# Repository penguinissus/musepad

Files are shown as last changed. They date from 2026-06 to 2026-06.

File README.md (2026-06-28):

# Musepad
This is a macropad that is built for helping with complicated functions when writing music in MuseScore. This macropad also features a compact and minimalistic design so it looks nice, and a plateless design which uses less material and provides more flex to each individual key.  

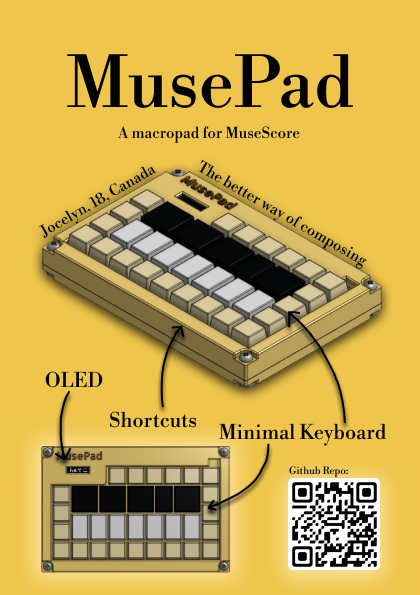
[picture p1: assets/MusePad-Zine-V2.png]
Zine
  

# User Instructions
Assembly:  
1. print out and buy all the parts found in `MusePad BOM.csv`   
2. solder everything together  
3. put in the keycaps accordingly (please refer to `3d models prints/Full Assembly.step` or reference pictures below for ideal layout)  
4. connect the oled to the pins on the PCB using jumper wires
5. sandwich pcb between the top and the bottom case  

Firmware:  
1. go to [circuitpython.org/downloads](circuitpython.org/downloads)    
2. download circuitpython for raspberry pi pico  
3. plug in keyboard to laptop and make sure to use a data transmitting cable  
4. open up the pico folder in your computer's directory  
5. replace the content of `code.py` in the pico folder with the one in this repo (`root://code/code.py`) 

# Why and how did I make it
I love composing music, and MuseScore is one great free composing software. However, whenever I want to compose efficiently, musescore hinders me significantly. Each detail I add to the music either requires too much shortcut memorization or it would take ages to find so I built MusePad to solve this problem. 

I first came up with some drawings of the design to make sure I knew how the layout kind of looked like. Then I made the schematic and PCB design on keycad, mostly following a tutorial (refer to the first resource link). I made the CAD on onshape mostly using skills I already had based on my past experiences, and for details that I don't really know, I referenced the hackpad guide (link no.2 in resource section). I also learned how to cad a keycap following a youtube tutorial (link no.3) which was really interesting. 

# Diagrams
Schematic Diagram:  
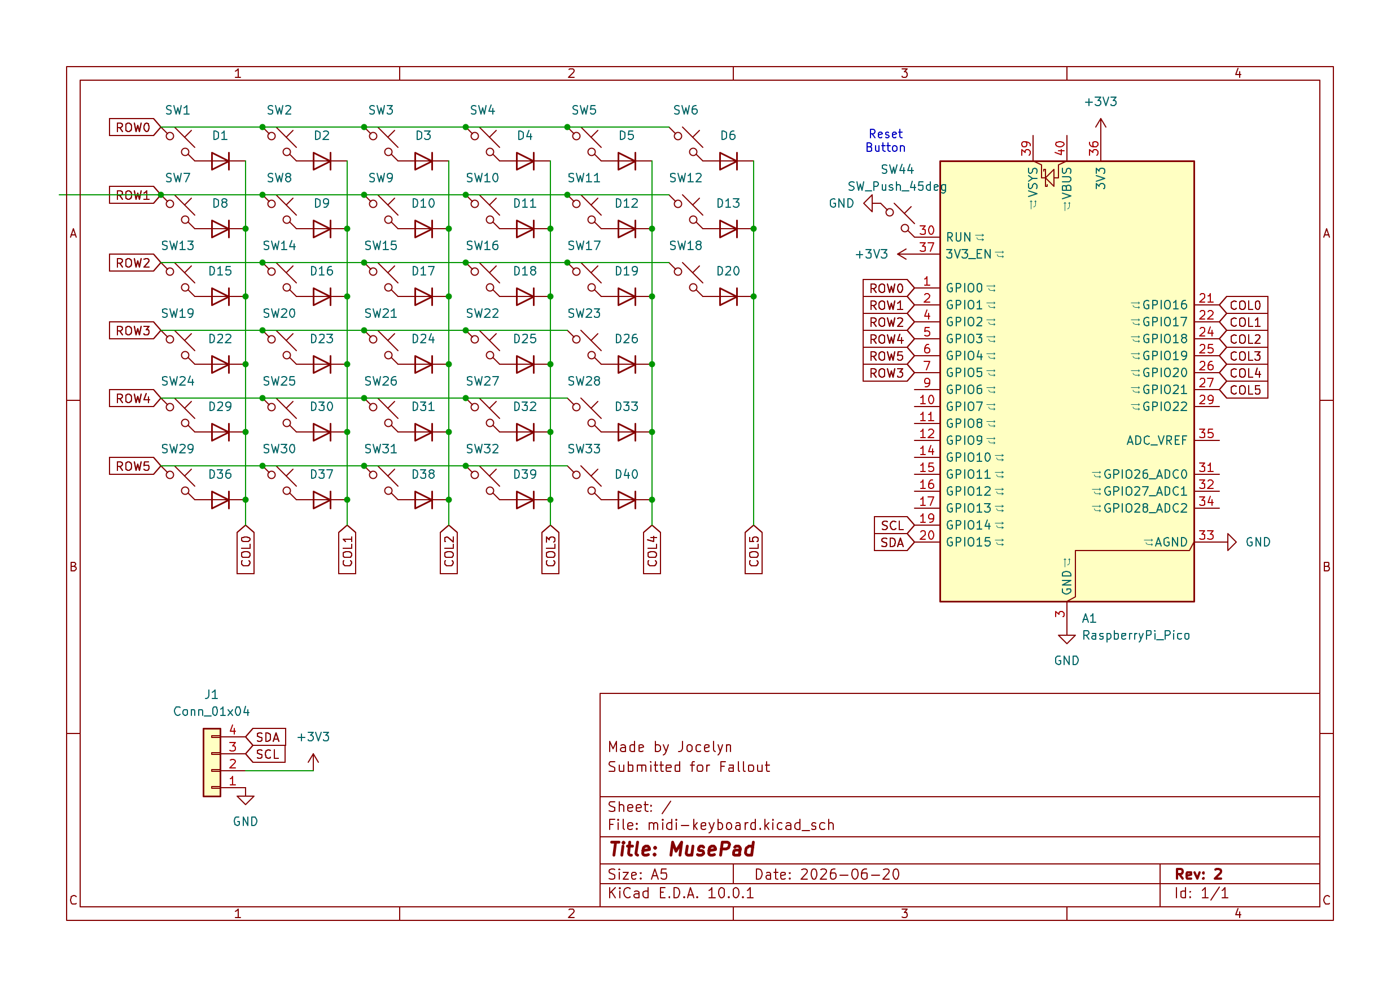
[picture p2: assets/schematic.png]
Schematic Diagram
  
PCB Editor View:  
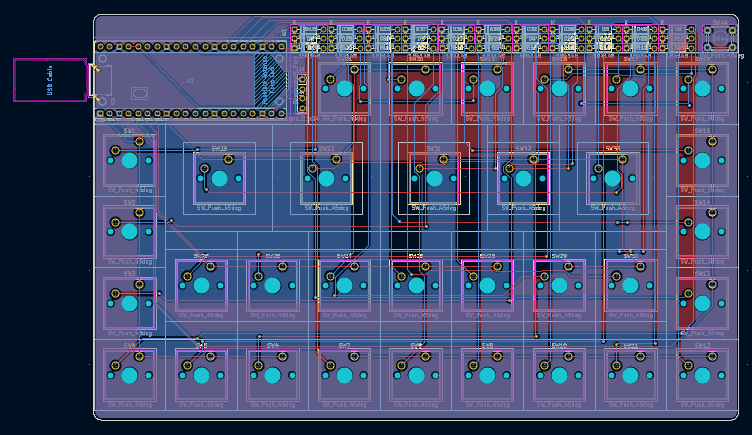
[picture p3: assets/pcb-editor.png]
PCB Editor View
  
PCB Model:  
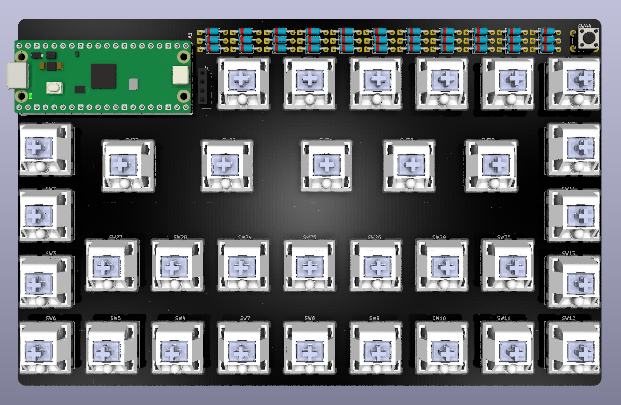
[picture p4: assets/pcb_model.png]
PCB Model
  
Assembled Model:  
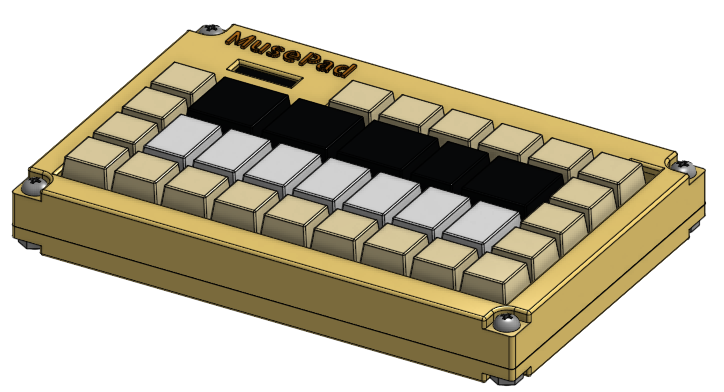
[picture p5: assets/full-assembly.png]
3D Model
  

# Resources
1. the blueprint tutorial  
2. hackpad guide  
3. youtube

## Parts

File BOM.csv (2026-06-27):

 | # | Price | Details
CHERRY MX | 33 | $5.63 | Any would work | https://www.amazon.ca/Mechanical-Keyboard-Switches-Compatible-Replaceable/dp/B0GT96R2XL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
Diodes | 33 | $3.65 | 1N4148 | https://www.amazon.ca/Switching-Electronic-Conponents-Assortment-Practical/dp/B0GJL8PR9D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
Push Button | 1 | $1.95 | 6mm | https://www.amazon.ca/Yevison-Tactile-Momentary-Button-Creative/dp/B0816XTT2P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
Raspberry Pi Pico | 1 | $6.85 | https://www.amazon.ca/CorpShadow-RPIPICO-Raspberry-Pi-Pico/dp/B09YJ34CK3
OLED Display | 1 | $4.94 | 0.91 Inch White OLED Display Module I2C Interface |  | https://www.amazon.ca/Serial-Display-Module-128X64-SSD1306/dp/B08F7M2RZ9
PCB | 1 | $12.30 | https://github.com/penguinissus/musepad/tree/main/production
Case Bottom | 1 | $0.00 | https://github.com/penguinissus/musepad/blob/main/3d%20models%20prints/Case%20Bottom.step
Case Top | 1 | $0.00 | https://github.com/penguinissus/musepad/blob/main/3d%20models%20prints/Case%20Top.step
Keycap normal size | 21 | $0.00 | https://github.com/penguinissus/musepad/blob/main/3d%20models%20prints/Keycap%201x1.step
Keycap white tall | 7 | $0.00 | https://github.com/penguinissus/musepad/blob/main/3d%20models%20prints/Keycap%201x1.5.step
Keycap black tall | 1 | $0.00 | https://github.com/penguinissus/musepad/blob/main/3d%20models%20prints/Keycap%201x1.5%20Black.step
Keycap black fat | 4 | $0.00 | https://github.com/penguinissus/musepad/blob/main/3d%20models%20prints/Keycap%201.5x1.5%20Black.step
Total price | $35.32

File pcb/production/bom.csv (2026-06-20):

Designator | Footprint | Quantity | Value | LCSC Part #
A1 | RaspberryPi_Pico_Common_THT | 1 | RaspberryPi_Pico
D1, D10, D11, D12, D13, D15, D16, D17, D18, D19, D2, D20, D22, D23, D24, D25, D26, D29, D3, D30, D31, D32, D33, D36, D37, D38, D39, D4, D40, D5, D6, D8, D9 | D_DO-35_SOD27_P7.62mm_Horizontal | 33 | 1N4148
J1 | PinSocket_1x04_P2.54mm_Vertical | 1 | Conn_01x04
SW1, SW10, SW11, SW12, SW13, SW14, SW15, SW16, SW17, SW18, SW19, SW2, SW20, SW21, SW22, SW23, SW24, SW25, SW26, SW27, SW28, SW29, SW3, SW30, SW31, SW32, SW33, SW4, SW5, SW6, SW7, SW8, SW9 | SW_Cherry_MX_1.00u_PCB | 33 | SW_Push_45deg
SW44 | SW_PUSH_6mm | 1 | SW_Push_45deg

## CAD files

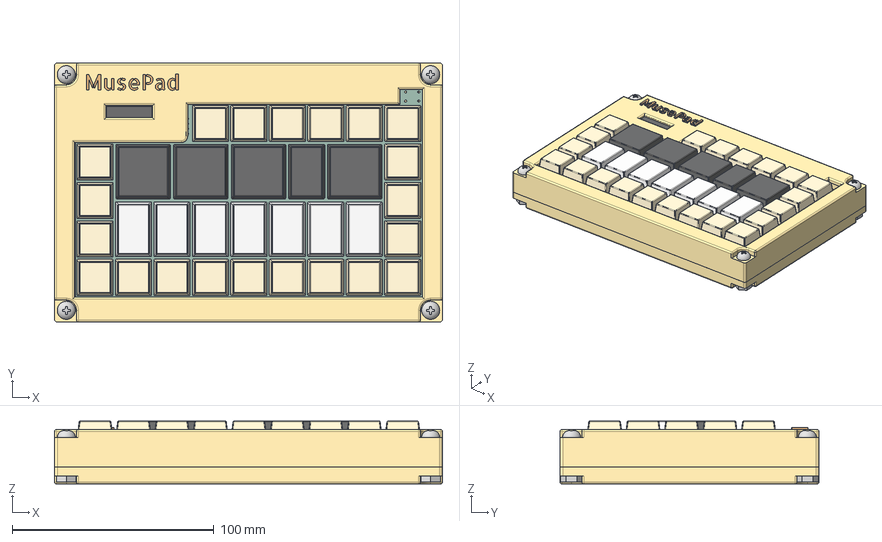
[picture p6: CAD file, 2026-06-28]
3d-models-prints/Full-Assembly.step
192.2 x 128.4 x 31.2 mm
midi-keyboard_PCB

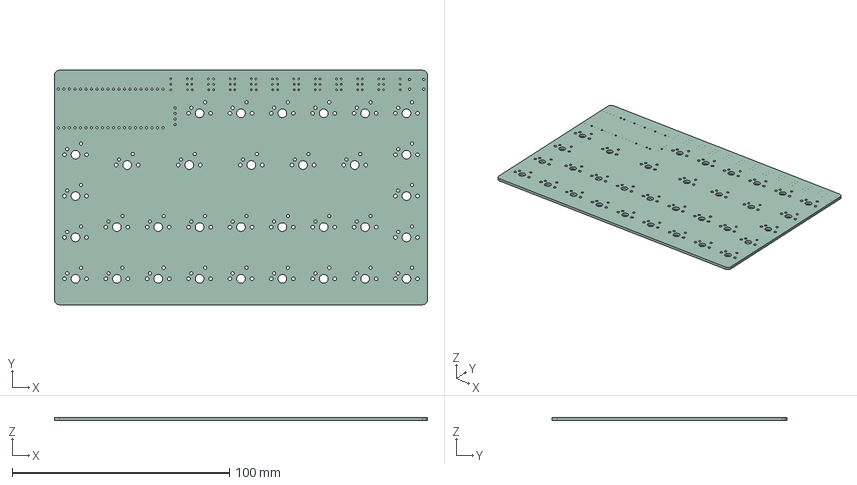
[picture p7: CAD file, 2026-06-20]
.step
171.8 x 108.0 x 1.51 mm

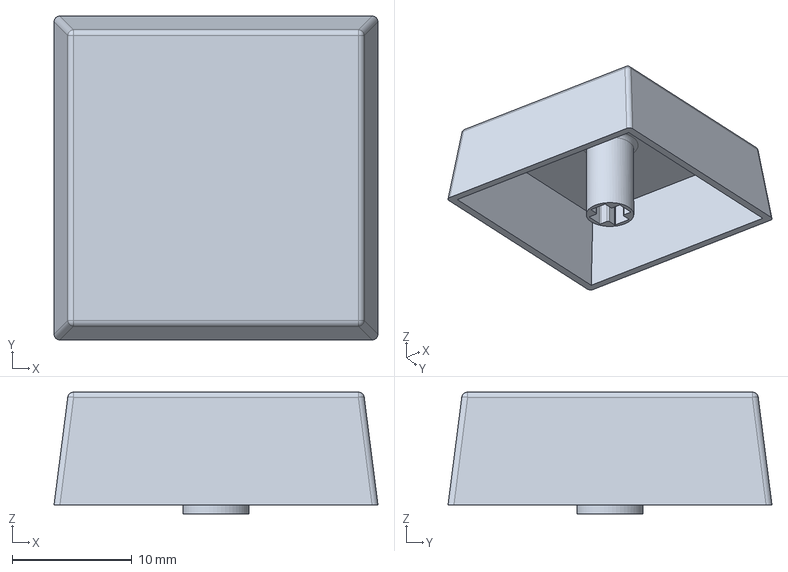
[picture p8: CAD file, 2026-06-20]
3d-models-prints/Keycap-1.5x1.5-Black.step
27.0 x 27.0 x 10.2 mm

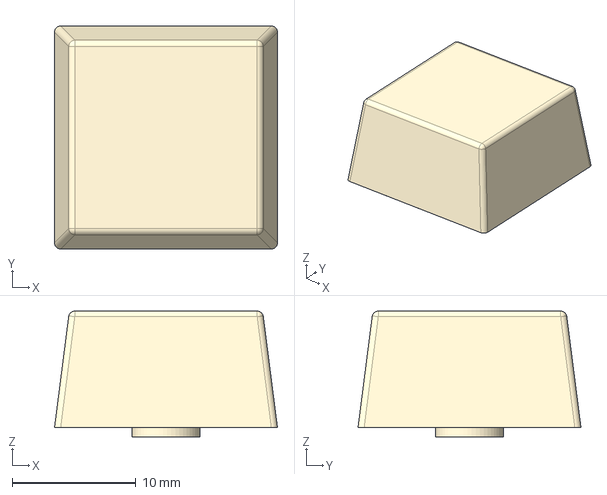
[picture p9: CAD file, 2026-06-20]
3d-models-prints/Keycap-1x1.step
18.0 x 18.0 x 10.2 mm

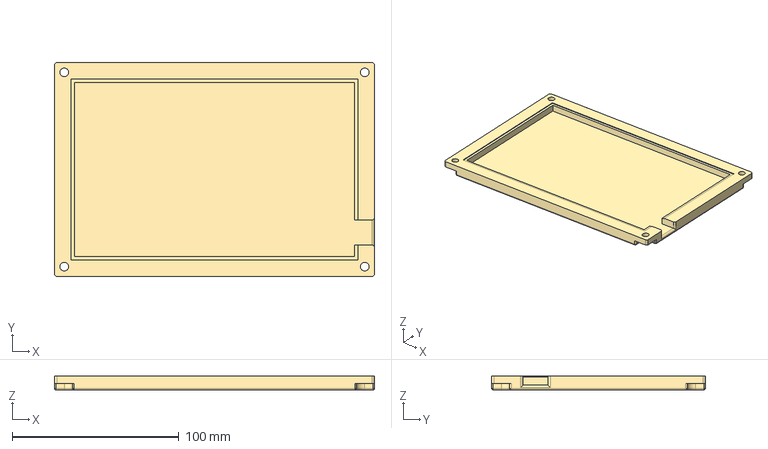
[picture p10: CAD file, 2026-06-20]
3d-models-prints/Case-Bottom.step
192.1 x 128.4 x 8.50 mm

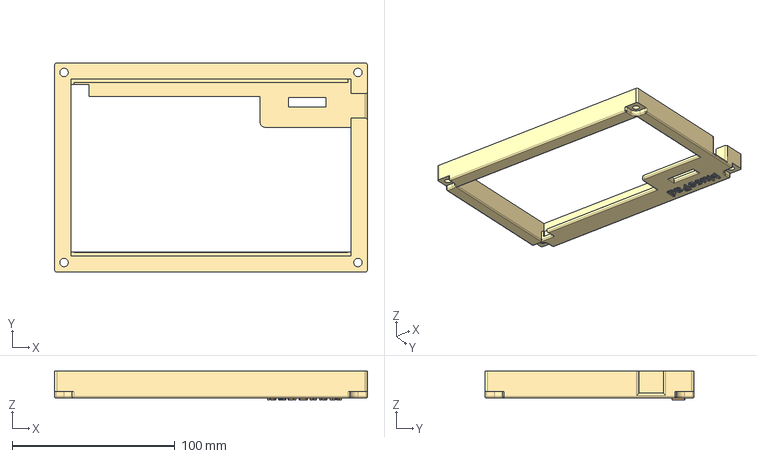
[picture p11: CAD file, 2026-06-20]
3d-models-prints/Case-Top.step
192.1 x 128.4 x 17.5 mm

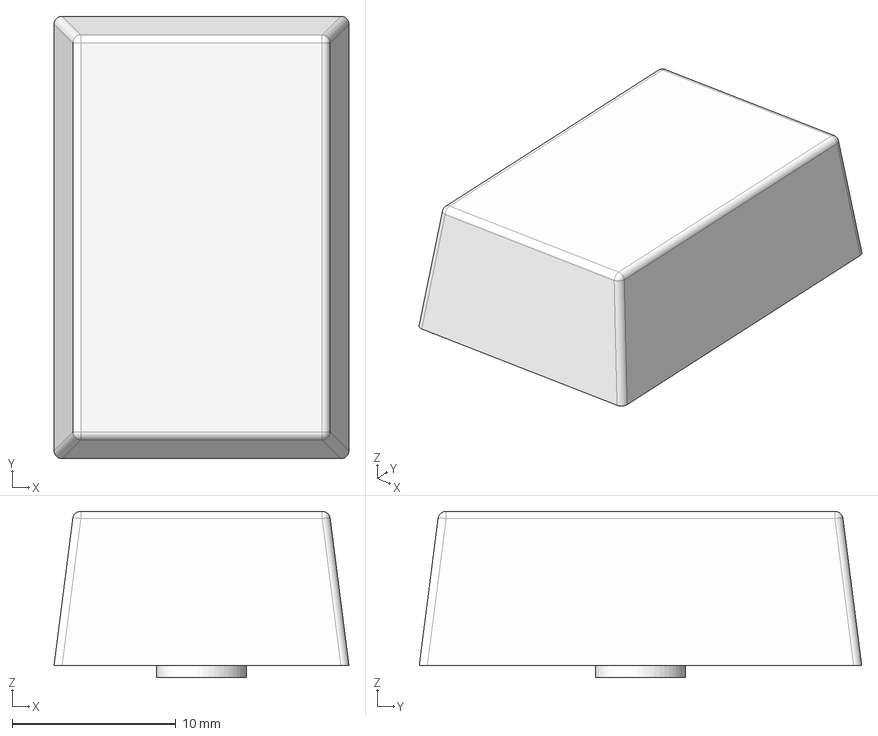
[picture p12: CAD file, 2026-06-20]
3d-models-prints/Keycap-1x1.5.step
18.0 x 27.0 x 10.2 mm

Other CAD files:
3d-models-prints/Keycap-1x1.5-Black.step

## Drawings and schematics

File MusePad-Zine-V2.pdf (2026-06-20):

# MusePad

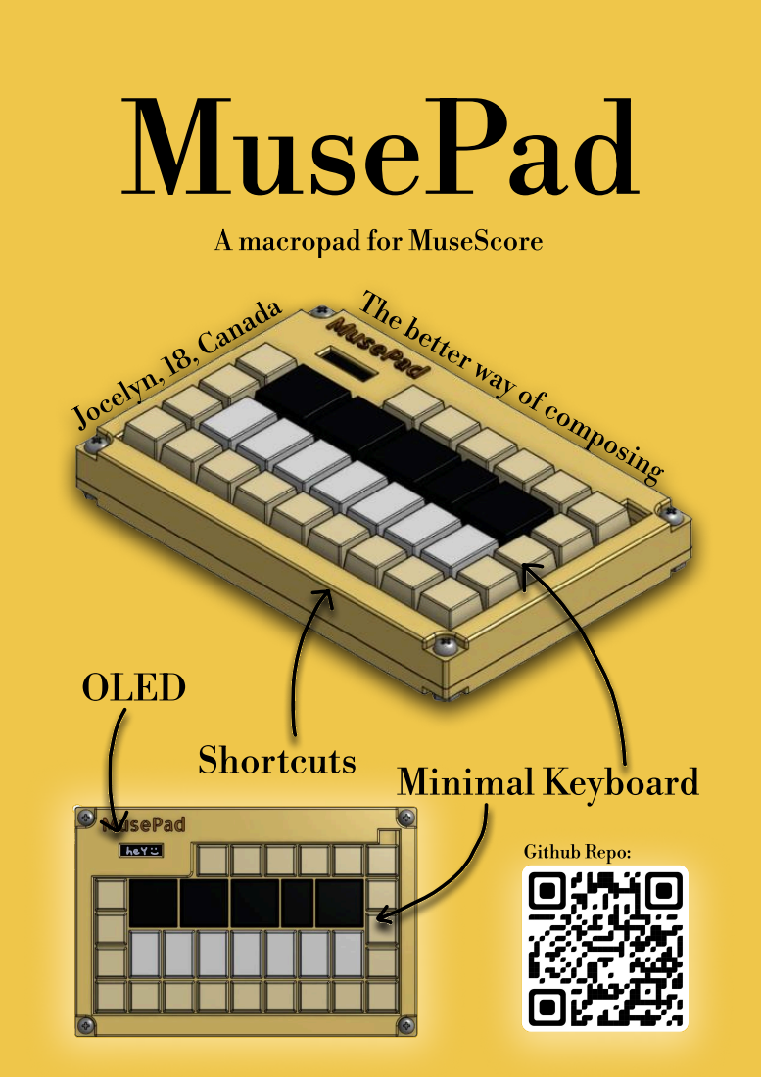
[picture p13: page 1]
Github Repo:

A macropad for MuseScore

OLED
Shortcuts Minimal Keyboard

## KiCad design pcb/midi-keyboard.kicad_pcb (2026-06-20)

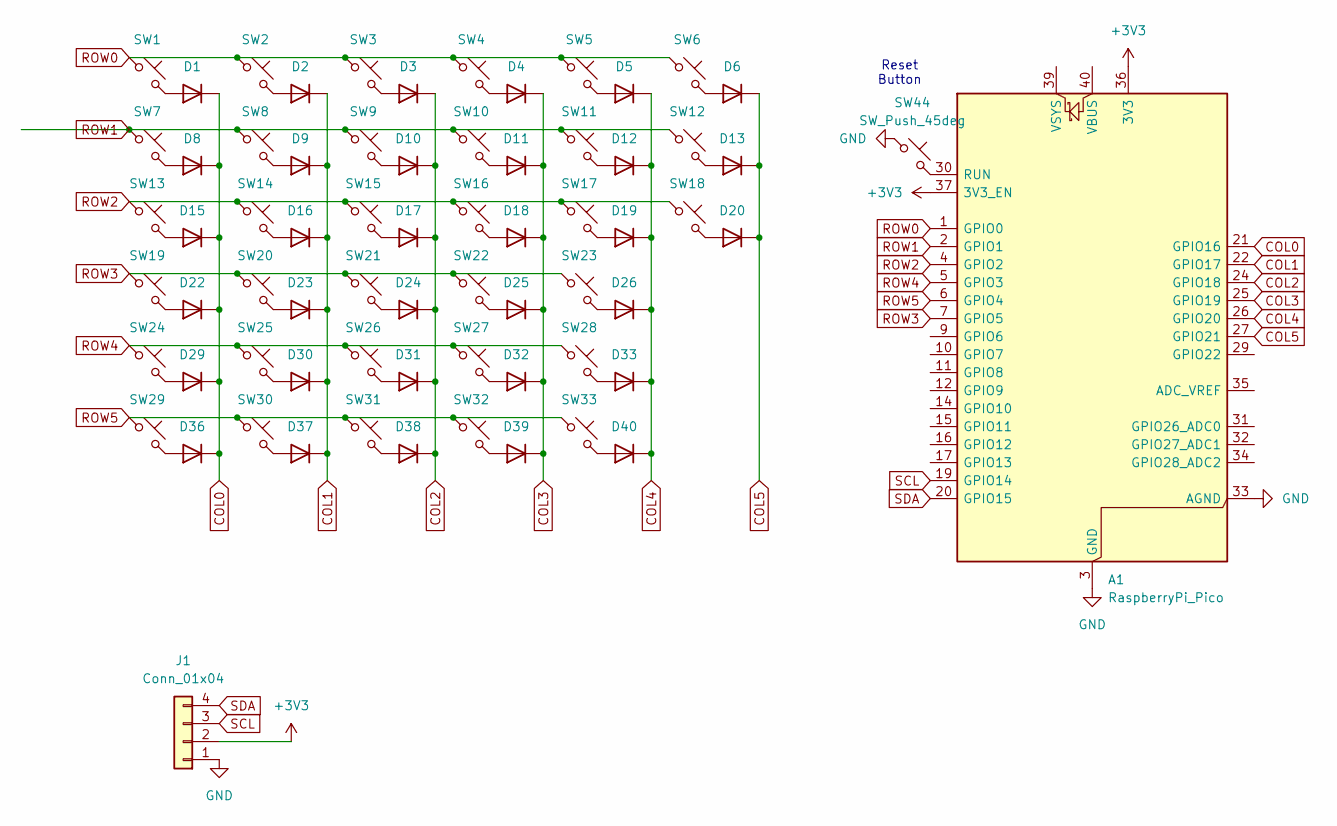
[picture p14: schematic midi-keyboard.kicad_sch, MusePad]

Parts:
A1: RaspberryPi_Pico; RaspberryPi_Pico_Common_THT
D1, D2, D3, D4, D5, D6, D8, D9, D10, D11, D12, D13, D15, D16, D17, D18, D19, D20, D22, D23, D24, D25, D26, D29, D30, D31, D32, D33, D36, D37, D38, D39, D40: 1N4148; D_DO-35_SOD27_P7.62mm_Horizontal
J1: Conn_01x04; PinSocket_1x04_P2.54mm_Vertical
SW1, SW2, SW3, SW4, SW5, SW6, SW7, SW8, SW9, SW10, SW11, SW12, SW13, SW14, SW15, SW16, SW17, SW18, SW19, SW20, SW21, SW22, SW23, SW24, SW25, SW26, SW27, SW28, SW29, SW30, SW31, SW32, SW33: SW_Push_45deg; SW_Cherry_MX_1.00u_PCB
SW44: SW_Push_45deg; SW_PUSH_6mm

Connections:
+3V3: A1.36 (3V3), A1.37 (3V3_EN), J1.2
COL0: A1.21 (GPIO16), D1.1 (K), D8.1 (K), D15.1 (K), D22.1 (K), D29.1 (K), D36.1 (K)
COL1: A1.22 (GPIO17), D2.1 (K), D9.1 (K), D16.1 (K), D23.1 (K), D30.1 (K), D37.1 (K)
COL2: A1.24 (GPIO18), D3.1 (K), D10.1 (K), D17.1 (K), D24.1 (K), D31.1 (K), D38.1 (K)
COL3: A1.25 (GPIO19), D4.1 (K), D11.1 (K), D18.1 (K), D25.1 (K), D32.1 (K), D39.1 (K)
COL4: A1.26 (GPIO20), D5.1 (K), D12.1 (K), D19.1 (K), D26.1 (K), D33.1 (K), D40.1 (K)
COL5: A1.27 (GPIO21), D6.1 (K), D13.1 (K), D20.1 (K)
GND: A1.3 (GND), A1.8 (GND), A1.13 (GND), A1.18 (GND), A1.23 (GND), A1.28 (GND), A1.33 (AGND), A1.38 (GND), J1.1, SW44.1
unnamed: A1.30 (RUN), SW44.2
unnamed: D1.2 (A), SW1.2
unnamed: D2.2 (A), SW2.2
unnamed: D3.2 (A), SW3.2
unnamed: D4.2 (A), SW4.2
unnamed: D5.2 (A), SW5.2
unnamed: D6.2 (A), SW6.2
unnamed: D8.2 (A), SW7.2
unnamed: D9.2 (A), SW8.2
unnamed: D10.2 (A), SW9.2
unnamed: D11.2 (A), SW10.2
unnamed: D12.2 (A), SW11.2
unnamed: D13.2 (A), SW12.2
unnamed: D15.2 (A), SW13.2
unnamed: D16.2 (A), SW14.2
unnamed: D17.2 (A), SW15.2
unnamed: D18.2 (A), SW16.2
unnamed: D19.2 (A), SW17.2
unnamed: D20.2 (A), SW18.2
unnamed: D22.2 (A), SW19.2
unnamed: D23.2 (A), SW20.2
unnamed: D24.2 (A), SW21.2
unnamed: D25.2 (A), SW22.2
unnamed: D26.2 (A), SW23.2
unnamed: D29.2 (A), SW24.2
unnamed: D30.2 (A), SW25.2
unnamed: D31.2 (A), SW26.2
unnamed: D32.2 (A), SW27.2
unnamed: D33.2 (A), SW28.2
unnamed: D36.2 (A), SW29.2
unnamed: D37.2 (A), SW30.2
unnamed: D38.2 (A), SW31.2
unnamed: D39.2 (A), SW32.2
unnamed: D40.2 (A), SW33.2
ROW0: A1.1 (GPIO0), SW1.1, SW2.1, SW3.1, SW4.1, SW5.1, SW6.1
ROW1: A1.2 (GPIO1), SW7.1, SW8.1, SW9.1, SW10.1, SW11.1, SW12.1
ROW2: A1.4 (GPIO2), SW13.1, SW14.1, SW15.1, SW16.1, SW17.1, SW18.1
ROW3: A1.7 (GPIO5), SW19.1, SW20.1, SW21.1, SW22.1, SW23.1
ROW4: A1.5 (GPIO3), SW24.1, SW25.1, SW26.1, SW27.1, SW28.1
ROW5: A1.6 (GPIO4), SW29.1, SW30.1, SW31.1, SW32.1, SW33.1
SCL: A1.19 (GPIO14), J1.3
SDA: A1.20 (GPIO15), J1.4

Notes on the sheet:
Reset Button

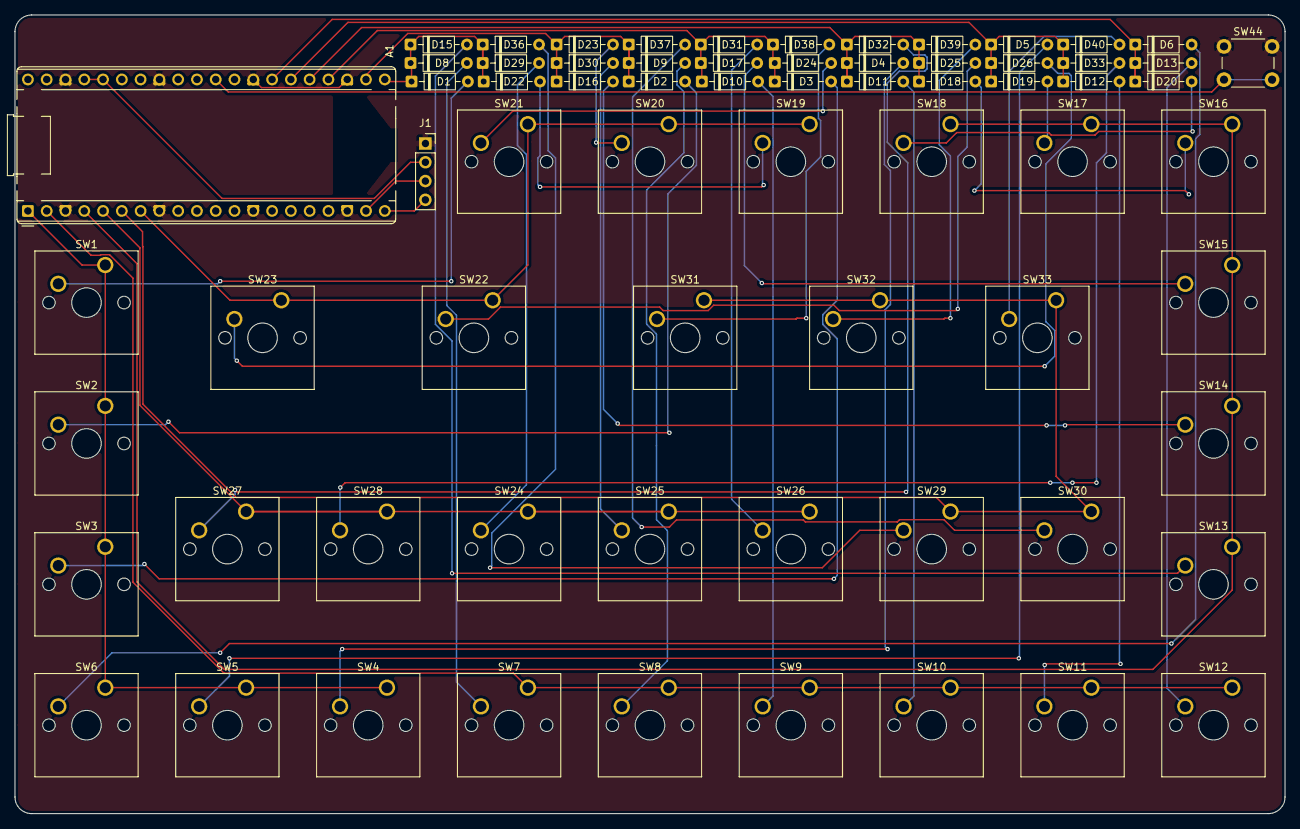
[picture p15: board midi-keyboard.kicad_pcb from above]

Board: 2 copper layers, 171.8 x 108.0 mm, 69 parts (0 on the bottom side), 50 nets.

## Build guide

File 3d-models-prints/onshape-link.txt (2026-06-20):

https://cad.onshape.com/documents/8381b665ed3e1ad59bcd28a3/w/75a472d5ec15a3be0e77d830/e/f28cb0cd25ec18a5a6ddd352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

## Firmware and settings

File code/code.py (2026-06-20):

import board
import keypad
import usb_hid
from adafruit_hid.keyboard import Keyboard
from adafruit_hid.keycode import Keycode

isSharp = False
isShift = False

# setup a keyboard device
kbd = Keyboard(usb_hid.devices)

rows = [board.GP0, board.GP1, board.GP2, board.GP5, board.GP3, board.GP4]
cols = [board.GP16, board.GP17, board.GP18, board.GP19, board.GP20, board.GP21]
matrix = keypad.KeyMatrix(rows, cols, columns_to_anodes=False)

# all print statements are for debugging purposes
while True:
    event = matrix.events.get()
    if event:
        if (event.key_number == 0):
            # octave up
            kbd.send(Keycode.CONTROL, Keycode.UP_ARROW)
        elif (event.key_number == 1):
            # octave down
            kbd.send(Keycode.CONTROL, Keycode.DOWN_ARROW)
        elif (event.key_number == 2):
            # toggle sharp flat
            isSharp = not isSharp
        elif (event.key_number == 3):
            # 8th notes
            kbd.send(Keycode.FOUR)
        elif (event.key_number == 4):
            # 16th notes
            kbd.send(Keycode.THREE)
        elif (event.key_number == 5):
            # fake shift
            isShift = not isShift
        elif (event.key_number == 6):
            # quarter note
            kbd.send(Keycode.FIVE)
        elif (event.key_number == 7):
            # half note
            kbd.send(Keycode.SIX)
        elif (event.key_number == 8):
            # whole note
            kbd.send(Keycode.SEVEN)
        elif (event.key_number == 9):
            # dotted note
            kbd.send(Keycode.PERIOD)
        elif event.key_number == 10:
            # rest
            kbd.send(Keycode.ZERO)
        elif event.key_number == 11:
            # tenuto
            kbd.send(Keycode.SHIFT, Keycode.N)
        elif event.key_number == 12:
            # staccato
            kbd.send(Keycode.SHIFT, Keycode.S)
        elif event.key_number == 13:
            # accent
            kbd.send(Keycode.SHIFT, Keycode.V)
        elif event.key_number == 14:
            # marcato
            kbd.send(Keycode.SHIFT, Keycode.O)
        elif event.key_number == 15:
            # tie
            kbd.send(Keycode.T)
        elif event.key_number == 16:
            # slur
            kbd.send(Keycode.S)
        elif event.key_number == 17:
            # chord naming
            kbd.send(Keycode.CONTROL, Keycode.K)
        elif event.key_number == 18:
            # decrescendo
            kbd.send(Keycode.SHIFT, Keycode.PERIOD)
        elif event.key_number == 19:
            # crescendo
            kbd.send(Keycode.SHIFT, Keycode.COMMA)
        elif event.key_number == 20:
            # dynamics
            kbd.send(Keycode.CONTROL, Keycode.D)
        elif event.key_number == 21:
            if isSharp:
                # d sharp
                kbd.send(Keycode.KEYPAD_PLUS)
                if isShift:
                    kbd.press(Keycode.SHIFT)
                kbd.send(Keycode.D)
                kbd.release(Keycode.SHIFT)
            else:
                # e flat
                kbd.send(Keycode.KEYPAD_MINUS)
                if isShift:
                    kbd.press(Keycode.SHIFT)
                kbd.send(Keycode.E)
                kbd.release(Keycode.SHIFT)
        elif event.key_number == 22:
            if isSharp:
                # C sharp
                kbd.send(Keycode.KEYPAD_PLUS)
                if isShift:
                    kbd.press(Keycode.SHIFT)
                kbd.send(Keycode.C)
                kbd.release(Keycode.SHIFT)
            else:
                # D flat
                kbd.send(Keycode.KEYPAD_MINUS)
                if isShift:
                    kbd.press(Keycode.SHIFT)
                kbd.send(Keycode.D)
                kbd.release(Keycode.SHIFT)
        elif event.key_number == 23:
            # E
            if isShift:
                kbd.press(Keycode.SHIFT)
            kbd.send(Keycode.E)
            kbd.release(Keycode.SHIFT)
        elif event.key_number == 24:
            # F
            if isShift:
                kbd.press(Keycode.SHIFT)
            kbd.send(Keycode.F)
            kbd.release(Keycode.SHIFT)
        elif event.key_number == 25:
            # G
            if isShift:
                kbd.press(Keycode.SHIFT)
            kbd.send(Keycode.G)
            kbd.release(Keycode.SHIFT)
        elif event.key_number == 26:
            # C
            if isShift:
                kbd.press(Keycode.SHIFT)
            kbd.send(Keycode.C)
            kbd.release(Keycode.SHIFT)
        elif event.key_number == 27:
            # D
            if isShift:
                kbd.press(Keycode.SHIFT)
            kbd.send(Keycode.D)
            kbd.release(Keycode.SHIFT)
        elif event.key_numbder == 28:
            # A
            if isShift:
                kbd.press(Keycode.SHIFT)
            kbd.send(Keycode.A)
            kbd.release(Keycode.SHIFT)
        elif event.key_number == 29:
            # B
            if isShift:
                kbd.press(Keycode.SHIFT)
            kbd.send(Keycode.B)
            kbd.release(Keycode.SHIFT)
        elif event.key_number == 30:
            if isSharp:
                # f sharp
                kbd.send(Keycode.KEYPAD_PLUS)
                if isShift:
                    kbd.press(Keycode.SHIFT)
                kbd.send(Keycode.F)
                kbd.release(Keycode.SHIFT)
            else:
                # g flat
                kbd.send(Keycode.KEYPAD_MINUS)
                if isShift:
                    kbd.press(Keycode.SHIFT)
                kbd.send(Keycode.G)
                kbd.release(Keycode.SHIFT)
        elif event.key_number == 31:
            if isSharp:
                # g sharp
                kbd.send(Keycode.KEYPAD_PLUS)
                if isShift:
                    kbd.press(Keycode.SHIFT)
                kbd.send(Keycode.G)
                kbd.release(Keycode.SHIFT)
            else:
                # a flat
                kbd.send(Keycode.KEYPAD_MINUS)
                if isShift:
                    kbd.press(Keycode.SHIFT)
                kbd.send(Keycode.A)
                kbd.release(Keycode.SHIFT)
        elif event.key_number == 32:
            if isSharp:
                # a sharp
                kbd.send(Keycode.KEYPAD_PLUS)
                if isShift:
                    kbd.press(Keycode.SHIFT)
                kbd.send(Keycode.A)
                kbd.release(Keycode.SHIFT)
            else:
                # b flat
                kbd.send(Keycode.KEYPAD_MINUS)
                if isShift:
                    kbd.press(Keycode.SHIFT)
                kbd.send(Keycode.B)
                kbd.release(Keycode.SHIFT)

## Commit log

2026-06-19 updated schematic
    [midi-keyboard.kicad_pcb, midi-keyboard.kicad_sch]
2026-06-19 finished pcb tracing
    [midi-keyboard.kicad_pcb, midi-keyboard.kicad_sch]
2026-06-20 added 3d model files
    [.step, Case Bottom.step, Case Top.step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]
2026-06-20 add 3d model
    [Keycap 1.5x1.5 Black.step]
2026-06-20 production files
    [bom.csv, designators.csv, positions.csv]
2026-06-20 swap keys
    [midi-keyboard.kicad_pcb, positions.csv]
2026-06-20 reorganize repo
    [.step, bom.csv, designators.csv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]
2026-06-27 update bom
    [BOM.csv, MusePad-BOM.csv]
2026-06-28 update cad
    [Full-Assembly.step]
